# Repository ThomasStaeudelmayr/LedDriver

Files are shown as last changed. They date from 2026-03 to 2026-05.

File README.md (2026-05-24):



This repository contains two distinct 4-channel LED driver hardware designs controlled by an **ESP32-S3 Zero**. Both versions support pulse-width modulation dimming.

- **Constant Current (CC) Driver:** Designed for high-power LEDs (like the Cree XLamp Color Series) that require current regulation.
    
- **Constant Voltage (CV) Driver:** Features 4 power MOSFETs designed for dimming standard 12V/24V RGBW LED strips.

## Hardware
### LED Driver CC

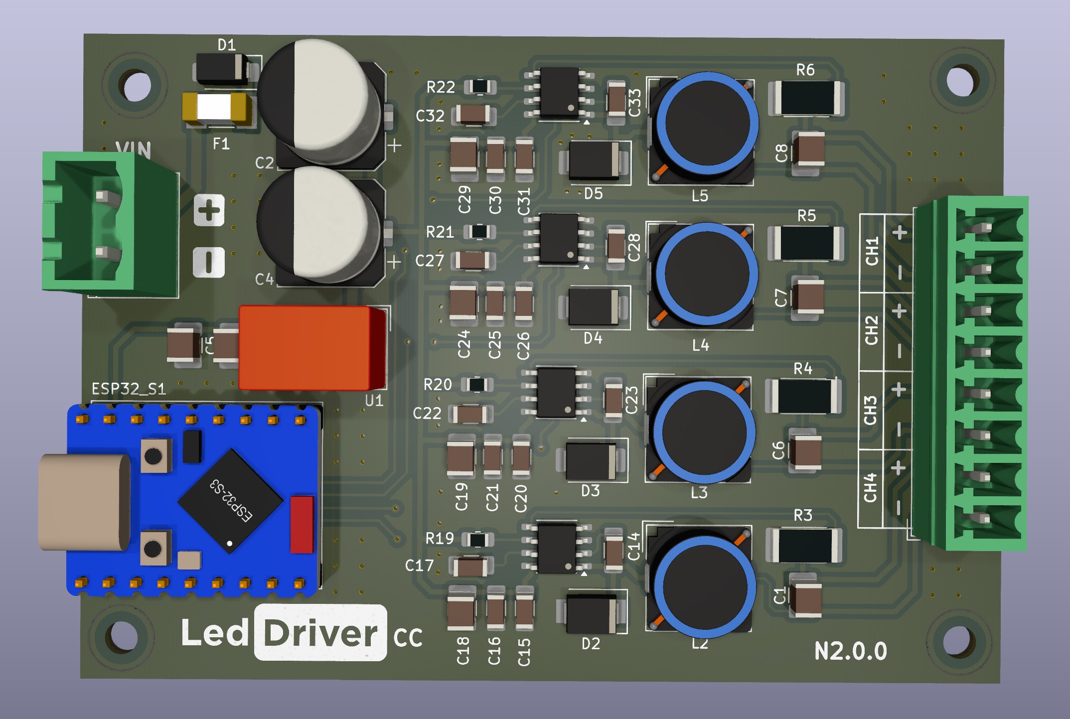
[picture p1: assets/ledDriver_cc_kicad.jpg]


The CC version is built around the **LM3404** LED driver IC. This is a step-down switching regulator that drives the connected LEDs in constant current mode, eliminating the need for current-limiting resistors and increasing system efficiency.
#### Current Sense Resistor Calculation
The maximum forward current ($I_F$) delivered to the LEDs is determined by the value of the sense resistor ($R_{SNS}$) connected to the `CS` pin. Use the following formula to select your resistor value:

$$R_{SNS} = \frac{V_{REF}}{I_F} = \frac{0.2\text{ V}}{I_F}$$

Using a 0.2 $\Omega$ resistor sets the maximum forward current to 1.0 A.

#### Parts
| Part name | Quantity | Order number | Distributor |
| --- | --- | --- | --- |
| ESP32-S3-Zero | 1 | B0GV459V87 | Amazon |
| LM3404 | 4 | LM 3404 MA | Reichelt |
| DK_SLF10145 47uH | 4 | 810-SLF10145T | Mouser |
| 0R2 2512 | 4 | 708-RNCL2512FTR200 | Mouser |
| SMAJ40A | 4 | 652-SMAJ40A | Mouser |
| DCDC Converter | 1 | LME78_05-1.0 | Reichelt |
| MCV_1,5_8-G-3.81 | 1 | 220-4888 | RS |
| Fuse 5A | 1 | 576-0454005.NR | Mouser |
| MSTBVA 2-G 5,08 | 1 | STBVA 2-G 5,08 | Reichelt |
| Capacitor 470uF 10x10 25V | 2 | - | - |
| Capacitor 470nF 1210 | 4 | - | - |
| Capacitor 2.2uF  1206 | 4 | - | - |
| Capacitor 100nF 1206 | 8 | - | - |
| Capacitor 10uF 1210 | 6 | - | - |
| Resistor 500k 0805 | 4 | - | - |

### LED Driver CV

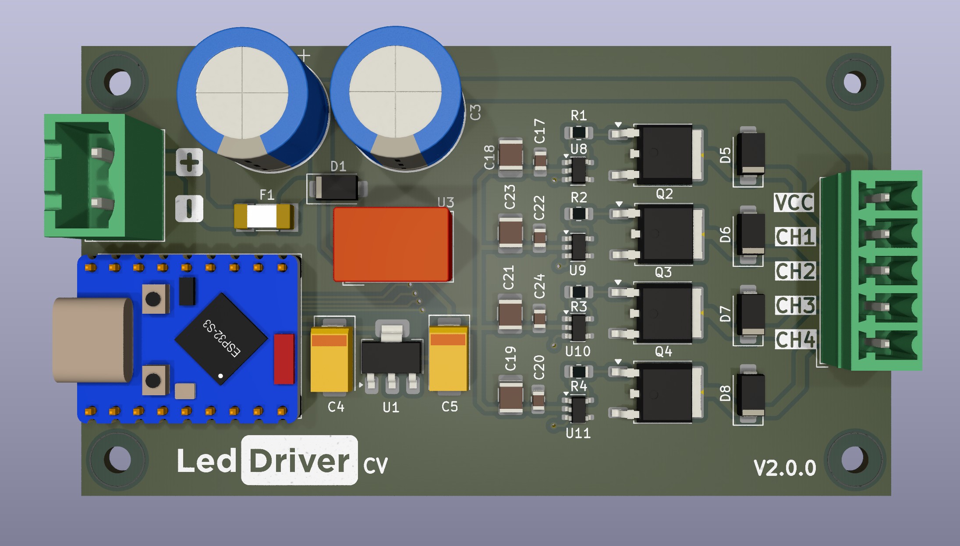
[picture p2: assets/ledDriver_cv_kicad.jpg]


The constant voltage version is designed for standard 12V/24V RGBW LED strips with integrated current-limiting resistors, utilizing 4 power MOSFETs as low-side switches. Dedicated gate drivers rapidly charge the MOSFET gate capacitance. The resulting fast rise and fall times minimize switching power losses during high-frequency PWM operation.
#### Parts
| Part name | Quantity | Order number | Distributor |
| --- | --- | --- | --- |
| ESP32-S3-Zero | 1 | B0GV459V87 | Amazon |
| MCV_1,5_5-G-3.81 | 1 | 651-1803455 | Mouser |
| MSTBVA 2-G 5,08 | 1 | STBVA 2-G 5,08 | Reichelt |
| Capacitor 470uF | 2 | FR-A 470U 63B | Reichelt |
| SMAJ40A | 5 | 652-SMAJ40A | Mouser |
| Tantal 7343 100uF | 2 | 80-T495D107M16ATE060 | Mouser |
| 5V LDO | 1 | 511-LD1117S50 | Mouser |
| 9V DCDC Converter | 1 | TSRN 1-2490 | Reichelt |
| MCP1416 SOT-23-5 | 4 | 579-MCP1416RTEOTVAO  | Mouser |
| Mosfet STD80N6F6 | 4 | 511-STD80N6F6 | Mouser |
| Fuse 5A | 1 | 576-0454005.NR | Mouser |
| Capacitor 10uF 1210  | 4 | - | - |
| Capacitor 100nF 0805 | 4 | - | - |
| Resistor 10R 0805 | 4 | - | - |

## Software 

### ESP-NOW Control Example

The PC sends color values over a USB serial connection to the **Led Driver Bridge**, which then wirelessly sends those values to the **Led Driver Receiver**. 
#### 1. Get the Receiver's MAC Address
To pair the devices, you need the unique MAC address of the receiver board.
1. Upload the **Receiver Code** to your LED driver board.
2. Open the Serial Monitor. On startup, the ESP32 will print its MAC address.
3. Copy this address; you will need it for the transmitter code.
    
#### 2. Transmitter/Bridge Configuration & Operation
The transmitter connects to your PC via USB, listens for incoming serial data, and forwards it wirelessly.
1. Open the **Transmitter Code**.
2. Replace the placeholder bytes with your receiver's MAC address
3. Upload the code to the transmitter ESP32. 

```cpp
// Example: Replace with your actual receiver MAC address
uint8_t broadcastAddress[] = {0x34, 0xB7, 0xDA, 0x5B, 0x58, 0xE0};
```

#### Sending Control Commands 
The bridge ESP expects a single string formatted as `R:G:B:W` followed by a newline character (`\n`).  

**Example:** `1024:255:150:360` 

You can type this manually into the Arduino Serial Monitor or automate it using a program. This repository contains two python and one html example that generate the rgbw values. Once the transmitter gets a valid message, it splits the string into individual color values and sends them out over ESP-NOW. 

**LedDriver_web_app_rgbw.html** - control leds via a browser 
**LedDriver_control_hsv.py** - control leds via a python script 
**LedDriver_rgbw_waves.py** - python script that generates led animation 

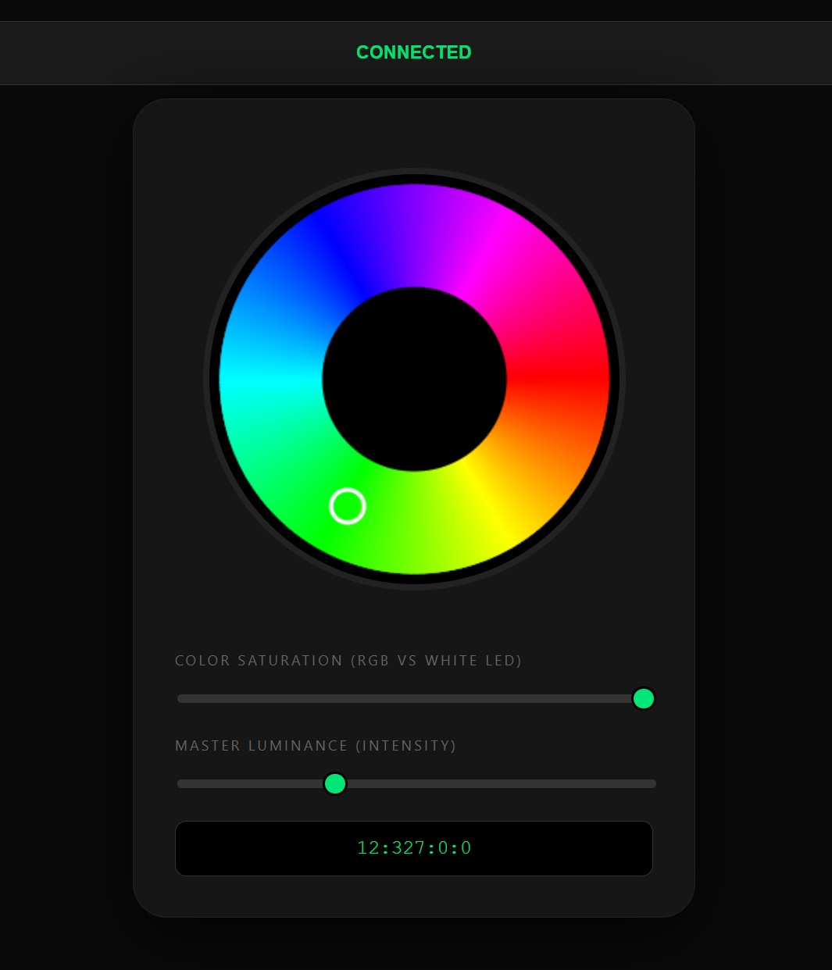
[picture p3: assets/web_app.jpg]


#### How to execute Python Scripts 
1. In folder open CMD
2. generate environment (python -m venv env)
3. open environment via activate.bat
4. install modules using pip
5. execute 

### Web Server Example
The Web Server example eliminates the need for a dedicated transmitter controller. The ESP32 on the driver board will act as a web server. After altering the Wi-Fi name and password and uploading the code the leds can be controlled on: http://ledcontrol.local

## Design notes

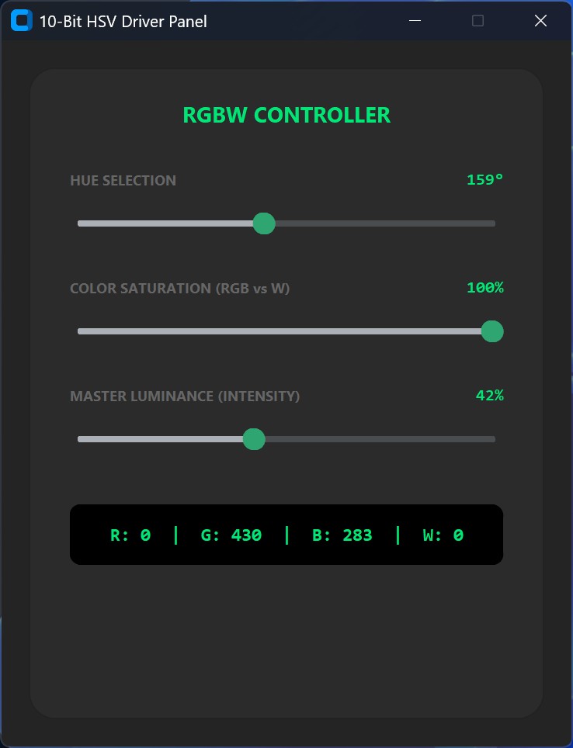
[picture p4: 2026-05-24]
assets/python_hsv_control.jpg

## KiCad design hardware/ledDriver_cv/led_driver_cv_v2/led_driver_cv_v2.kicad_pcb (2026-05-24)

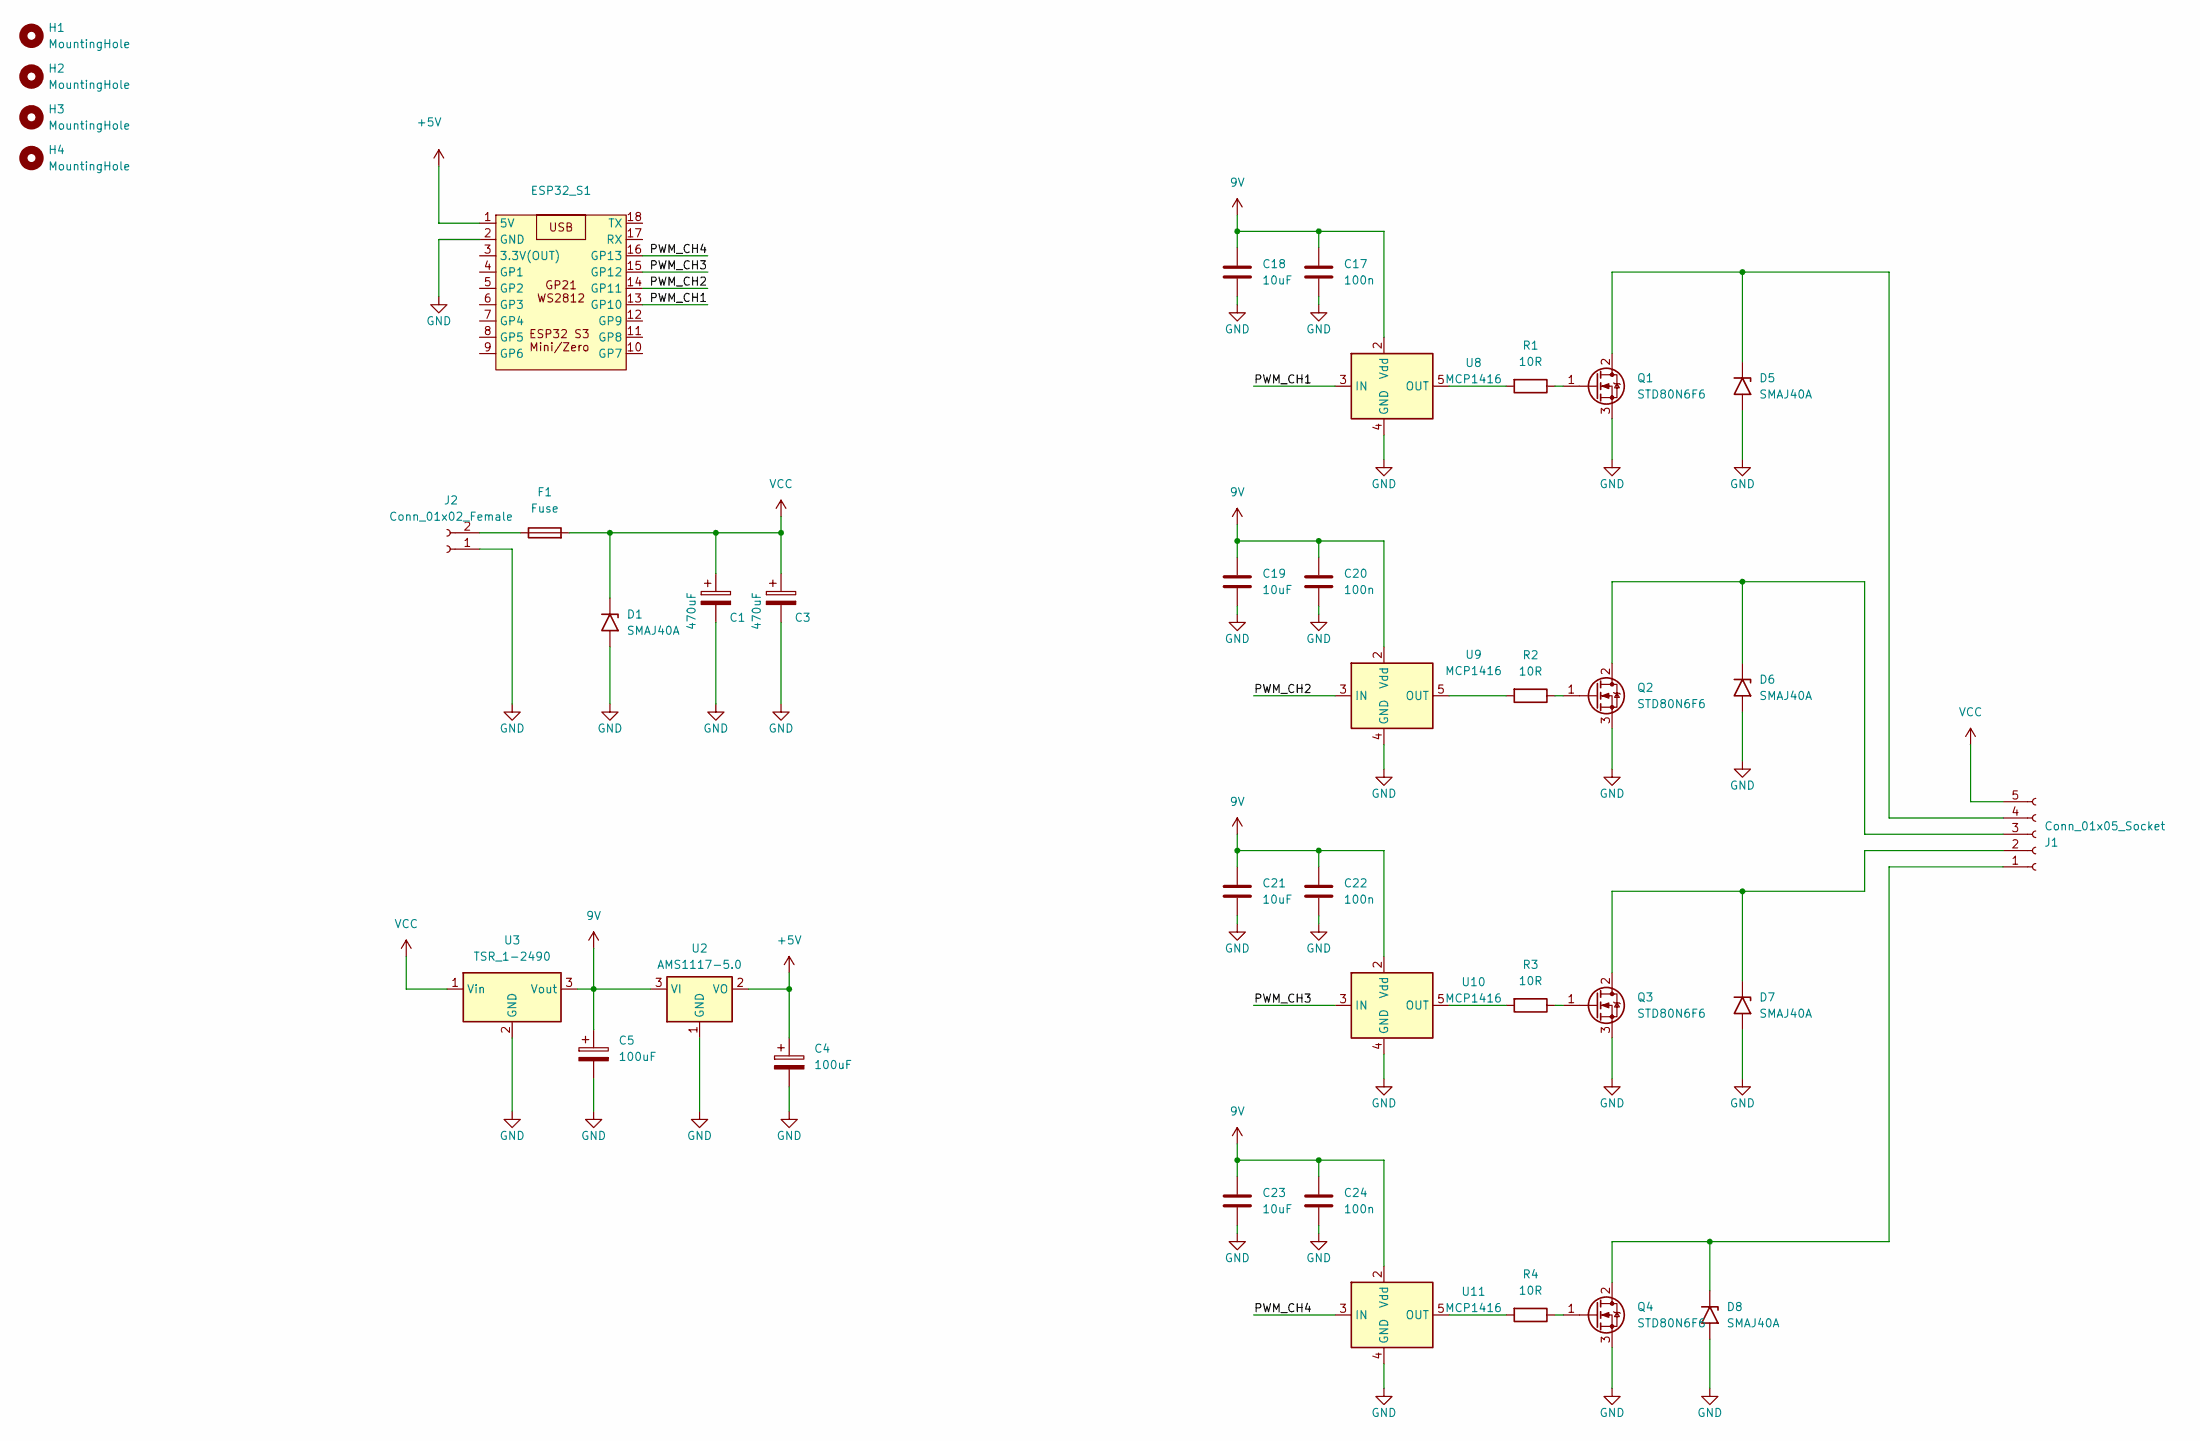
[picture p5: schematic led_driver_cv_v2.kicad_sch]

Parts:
C1, C3: 470uF; CP_Radial_D13.0mm_P5.00mm
C4, C5: 100uF; CP_EIA-7343-40_Kemet-Y_HandSolder
C17, C20, C22, C24: 100n; C_0805_2012Metric_Pad1.18x1.45mm_HandSolder
C18, C19, C21, C23: 10uF; C_1210_3225Metric_Pad1.33x2.70mm_HandSolder
D1, D5, D6, D7, D8: SMAJ40A; D_SMA
ESP32_S1: ESP32-S3-Zero
F1: Fuse; Fuse_Littelfuse-NANO2-451_453
H1: MountingHole; MountingHole_2.5mm
H2, H3, H4: MountingHole; MountingHole_3mm
J1: Conn_01x05_Socket; PhoenixContact_MCV_1,5_5-G-3.81_1x05_P3.81mm_Vertical
J2: Conn_01x02_Female; PhoenixContact_MSTBVA_2,5_2-G-5,08_1x02_P5.08mm_Vertical
Q1, Q2, Q3, Q4: STD80N6F6; TO-252-2
R1, R2, R3, R4: 10R; R_0805_2012Metric_Pad1.20x1.40mm_HandSolder
U2: AMS1117-5.0; SOT-223-3_TabPin2
U3: TSR_1-2490; Converter_DCDC_TRACO_TSR-1_THT
U8, U9, U10, U11: MCP1416; SOT-23-5

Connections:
9V: C5.1, C17.1, C18.1, C19.1, C20.1, C21.1, C22.1, C23.1, C24.1, U2.3 (VI), U3.3 (Vout), U8.2 (Vdd), U9.2 (Vdd), U10.2 (Vdd), U11.2 (Vdd)
+5V: C4.1, ESP32_S1.1 (5V), U2.2 (VO)
/PWM_CH1: ESP32_S1.13 (GP10), U8.3 (IN)
/PWM_CH2: ESP32_S1.14 (GP11), U9.3 (IN)
/PWM_CH3: ESP32_S1.15 (GP12), U10.3 (IN)
/PWM_CH4: ESP32_S1.16 (GP13), U11.3 (IN)
GND: C1.2, C3.2, C4.2, C5.2, C17.2, C18.2, C19.2, C20.2, C21.2, C22.2, C23.2, C24.2, D1.2 (A2), D5.2 (A2), D6.2 (A2), D7.2 (A2), D8.2 (A2), ESP32_S1.2 (GND), J2.1, Q1.3 (S), Q2.3 (S), Q3.3 (S), Q4.3 (S), U2.1 (GND), U3.2 (GND), U8.4 (GND), U9.4 (GND), U10.4 (GND), U11.4 (GND)
unnamed: D5.1 (A1), J1.4, Q1.2 (D)
unnamed: D6.1 (A1), J1.3, Q2.2 (D)
unnamed: D7.1 (A1), J1.2, Q3.2 (D)
unnamed: D8.1 (A1), J1.1, Q4.2 (D)
unnamed: F1.1, J2.2
unnamed: Q1.1 (G), R1.1
unnamed: Q2.1 (G), R2.1
unnamed: Q3.1 (G), R3.1
unnamed: Q4.1 (G), R4.1
unnamed: R1.2, U8.5 (OUT)
unnamed: R2.2, U9.5 (OUT)
unnamed: R3.2, U10.5 (OUT)
unnamed: R4.2, U11.5 (OUT)
VCC: C1.1, C3.1, D1.1 (A1), F1.2, J1.5, U3.1 (Vin)

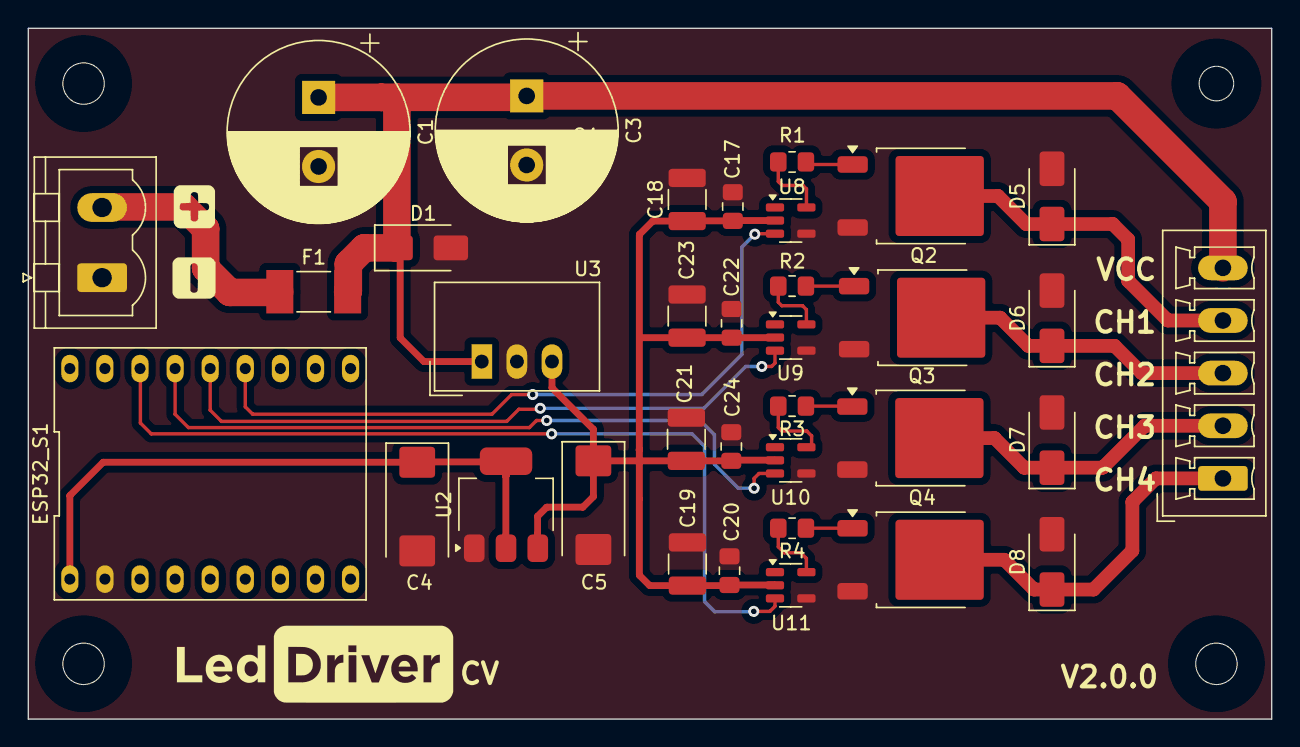
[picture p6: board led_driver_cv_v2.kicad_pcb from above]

Board: 2 copper layers, 90.0 x 50.0 mm, 39 parts (0 on the bottom side), 21 nets.

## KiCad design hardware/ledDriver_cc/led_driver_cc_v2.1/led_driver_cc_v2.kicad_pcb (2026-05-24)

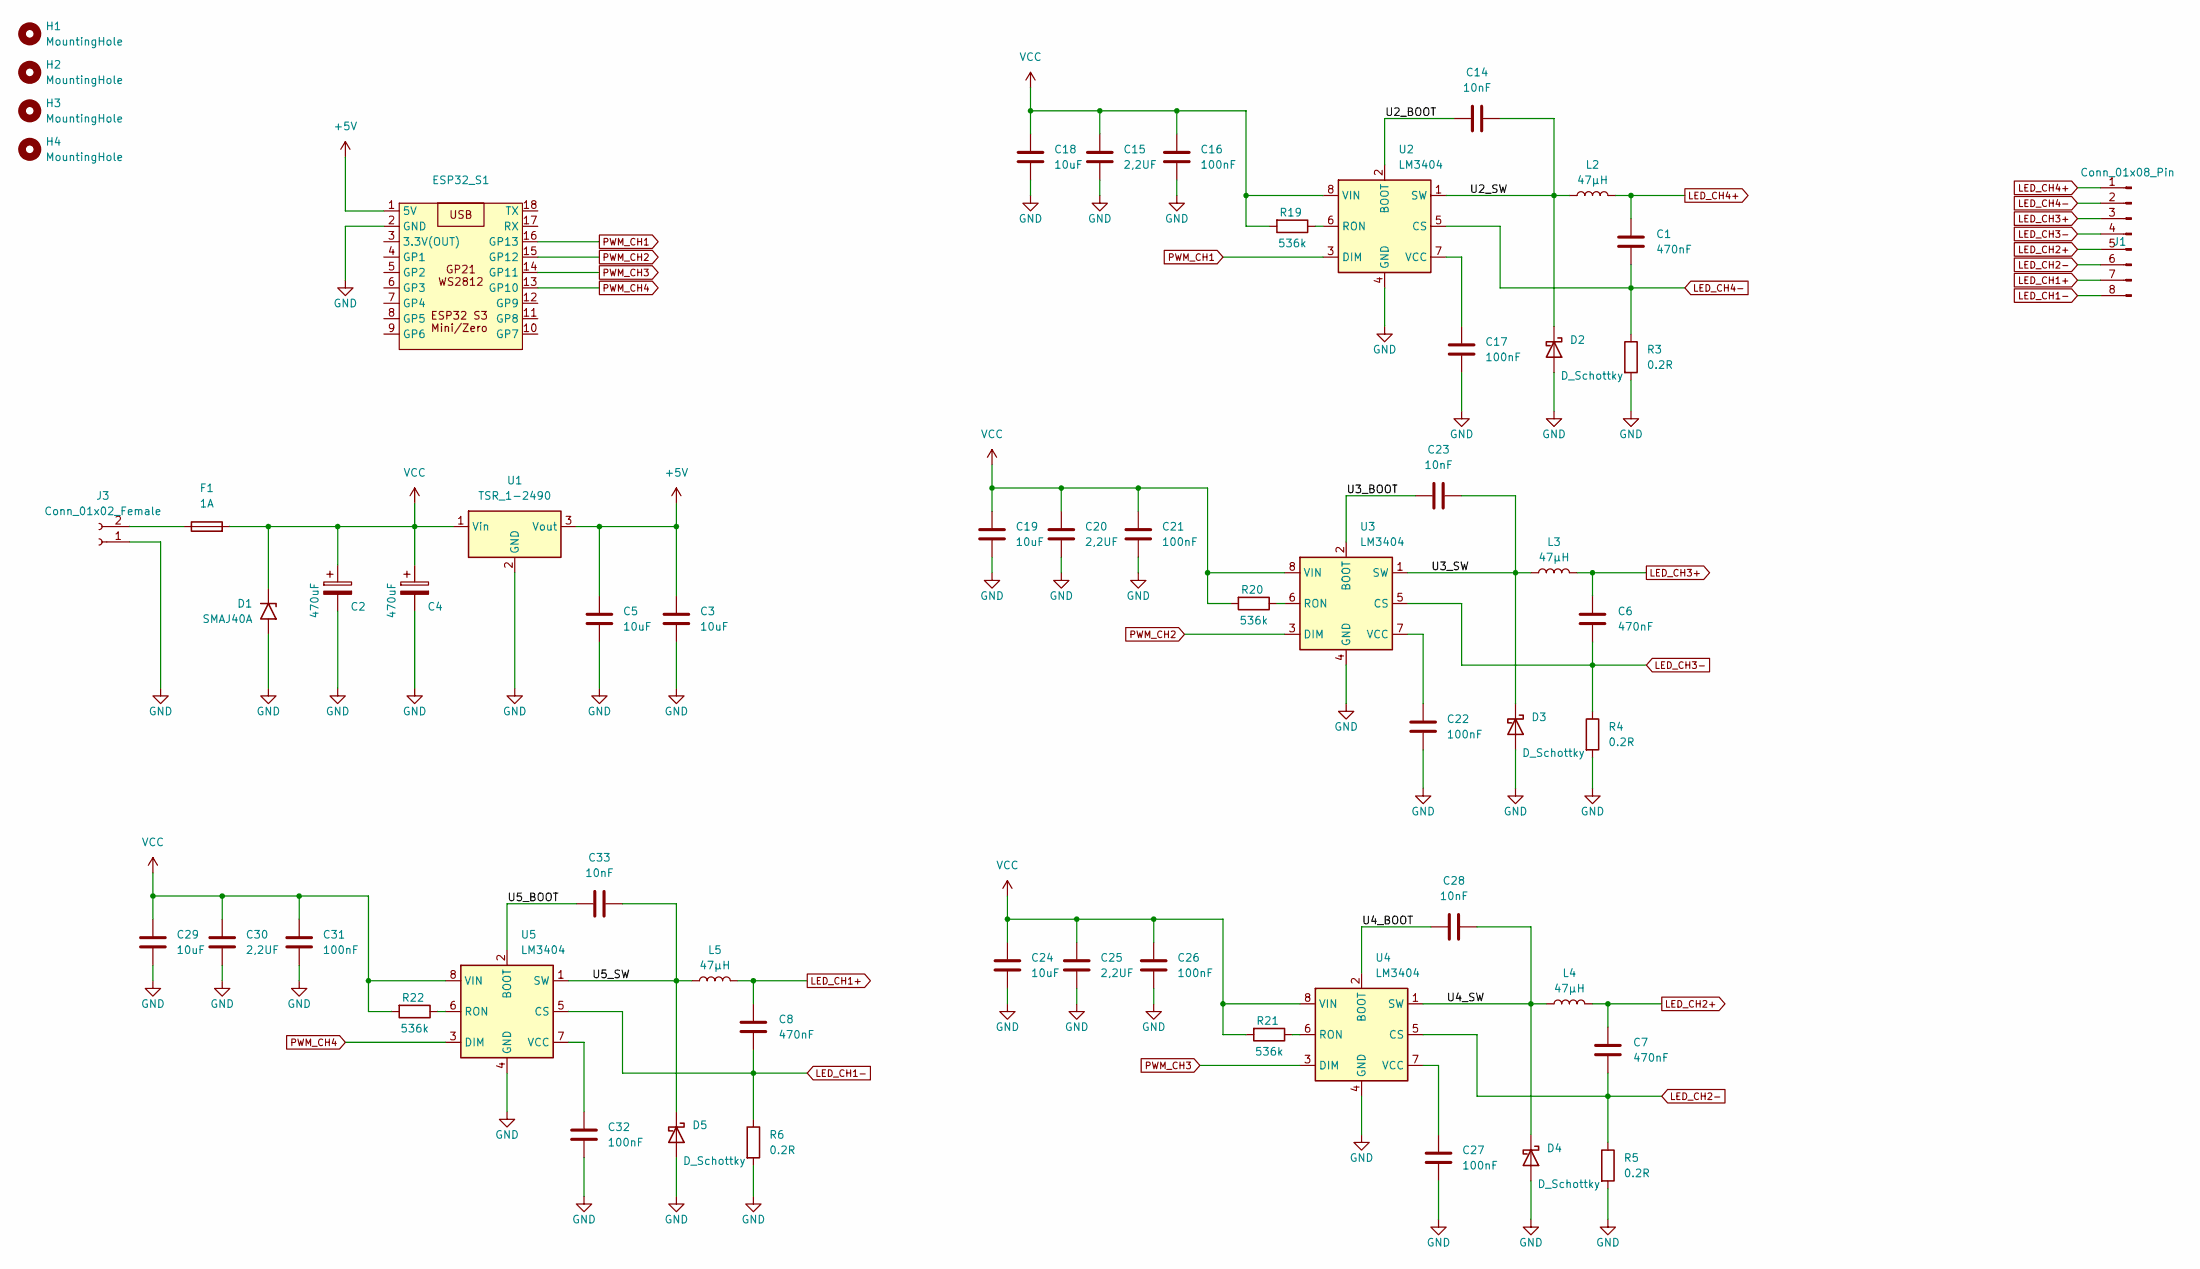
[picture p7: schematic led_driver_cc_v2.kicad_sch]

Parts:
C1, C6, C7, C8: 470nF; C_1210_3225Metric_Pad1.33x2.70mm_HandSolder
C2, C4: 470uF; CP_Elec_10x10
C3, C5, C18, C19, C24, C29: 10uF; C_1210_3225Metric_Pad1.33x2.70mm_HandSolder
C14, C23, C28, C33: 10nF; C_1206_3216Metric_Pad1.33x1.80mm_HandSolder
C15, C20, C25, C30: 2,2UF; C_1206_3216Metric_Pad1.33x1.80mm_HandSolder
C16, C17, C21, C22, C26, C27, C31, C32: 100nF; C_1206_3216Metric_Pad1.33x1.80mm_HandSolder
D1: SMAJ40A; D_SMA
D2, D3, D4, D5: D_Schottky; D_SMB
ESP32_S1: ESP32-S3-Zero
F1: 1A; Fuse_Littelfuse-NANO2-451_453
H1, H2, H3, H4: MountingHole; MountingHole_3.2mm_M3
J1: Conn_01x08_Pin; PhoenixContact_MCV_1,5_8-G-3.81_1x08_P3.81mm_Vertical
J3: Conn_01x02_Female; PhoenixContact_MSTBVA_2,5_2-G_1x02_P5.00mm_Vertical
L2, L3, L4, L5: 47µH; L_TDK_SLF10145
R3, R4, R5, R6: 0.2R; R_2512_6332Metric_Pad1.40x3.35mm_HandSolder
R19, R20, R21, R22: 536k; R_0805_2012Metric_Pad1.20x1.40mm_HandSolder
U1: TSR_1-2490; Converter_DCDC_TRACO_TSR-1_THT
U2, U3, U4, U5: LM3404; SOIC-8_3.9x4.9mm_P1.27mm

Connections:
+5V: C3.1, C5.1, ESP32_S1.1 (5V), U1.3 (Vout)
/U2_BOOT: C14.1, U2.2 (BOOT)
/U2_SW: C14.2, D2.1 (K), L2.1, U2.1 (SW)
/U3_BOOT: C23.1, U3.2 (BOOT)
/U3_SW: C23.2, D3.1 (K), L3.1, U3.1 (SW)
/U4_BOOT: C28.1, U4.2 (BOOT)
/U4_SW: C28.2, D4.1 (K), L4.1, U4.1 (SW)
/U5_BOOT: C33.1, U5.2 (BOOT)
/U5_SW: C33.2, D5.1 (K), L5.1, U5.1 (SW)
GND: C2.2, C3.2, C4.2, C5.2, C15.1, C16.1, C17.1, C18.1, C19.1, C20.1, C21.1, C22.1, C24.1, C25.1, C26.1, C27.1, C29.1, C30.1, C31.1, C32.1, D1.2 (A2), D2.2 (A), D3.2 (A), D4.2 (A), D5.2 (A), ESP32_S1.2 (GND), J3.1, R3.2, R4.2, R5.2, R6.2, U1.2 (GND), U2.4 (GND), U3.4 (GND), U4.4 (GND), U5.4 (GND)
LED_CH1+: C8.1, J1.7, L5.2
LED_CH1-: C8.2, J1.8, R6.1, U5.5 (CS)
LED_CH2+: C7.1, J1.5, L4.2
LED_CH2-: C7.2, J1.6, R5.1, U4.5 (CS)
LED_CH3+: C6.1, J1.3, L3.2
LED_CH3-: C6.2, J1.4, R4.1, U3.5 (CS)
LED_CH4+: C1.1, J1.1, L2.2
LED_CH4-: C1.2, J1.2, R3.1, U2.5 (CS)
unnamed: F1.1, J3.2
unnamed: R19.1, U2.6 (RON)
unnamed: C17.2, U2.7 (VCC)
unnamed: R20.1, U3.6 (RON)
unnamed: C22.2, U3.7 (VCC)
unnamed: R21.1, U4.6 (RON)
unnamed: C27.2, U4.7 (VCC)
unnamed: R22.1, U5.6 (RON)
unnamed: C32.2, U5.7 (VCC)
PWM_CH1: ESP32_S1.16 (GP13), U2.3 (DIM)
PWM_CH2: ESP32_S1.15 (GP12), U3.3 (DIM)
PWM_CH3: ESP32_S1.14 (GP11), U4.3 (DIM)
PWM_CH4: ESP32_S1.13 (GP10), U5.3 (DIM)
VCC: C2.1, C4.1, C15.2, C16.2, C18.2, C19.2, C20.2, C21.2, C24.2, C25.2, C26.2, C29.2, C30.2, C31.2, D1.1 (A1), F1.2, R19.2, R20.2, R21.2, R22.2, U1.1 (Vin), U2.8 (VIN), U3.8 (VIN), U4.8 (VIN), U5.8 (VIN)

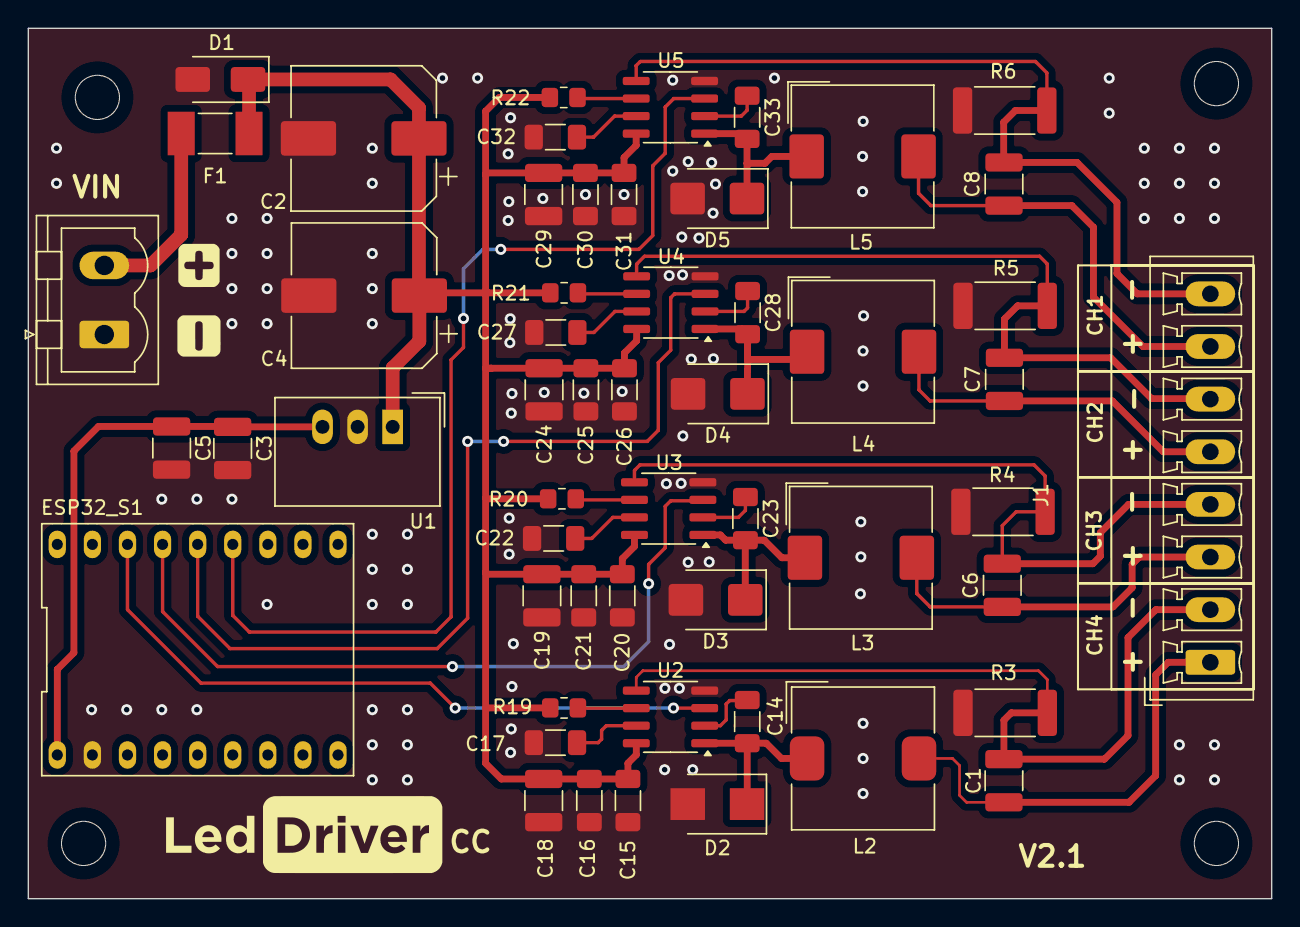
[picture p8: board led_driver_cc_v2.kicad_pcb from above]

Board: 2 copper layers, 90.0 x 63.0 mm, 58 parts (0 on the bottom side), 32 nets.

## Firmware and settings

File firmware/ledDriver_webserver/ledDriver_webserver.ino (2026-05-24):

/*
 * ====================================================================
 * Project:      RGBW Led Driver Controller
 * Description:  Hosts an internal web page allowing real-time adjustment
 * of 4 PWM channels.
 * Target Board: ESP32-S3 Zero
 * ====================================================================
 */

#include <WiFi.h>
#include <WebServer.h>
#include <ESPmDNS.h>

// --- WiFi Credentials ---
const char* ssid = "YOUR_WIFI_SSID";
const char* password = "YOUR_WIFI_PASSWORD";


// --- Pin & PWM Definitions ---
const int pins[] = {10, 11, 12, 13}; 

// Locked to your target hardware parameters
const uint32_t PWM_FREQ = 1000;  // 1 kHz Frequency
const uint8_t PWM_RES   = 10;    // 10-bit Resolution (0 - 1023)

WebServer server(80);

// HTML Dashboard String
const char PAGE_MAIN[] PROGMEM = R"=====(
<!DOCTYPE html>
<html>
<head>
    <meta name="viewport" content="width=device-width, initial-scale=1">
    <title>LED Dashboard</title>
    <style>
        body { font-family: sans-serif; text-align: center; background: #121212; color: white; padding: 20px; }
        .card { background: #1e1e1e; padding: 15px; border-radius: 12px; margin: 10px auto; max-width: 350px; border: 1px solid #333; }
        h2 { color: #00adb5; }
        input[type=range] { width: 100%; accent-color: #00adb5; cursor: pointer; }
        .val-display { font-size: 1.1em; margin-top: 5px; color: #00adb5; font-weight: bold; }
    </style>
</head>
<body>
    <h2>Led Driver Control</h2>
    <div class="card">
        <p>Channel 1 (red) </p>
        <input type="range" min="0" max="1023" value="0" oninput="update(1, this.value)">
        <div class="val-display" id="val1">0</div>
    </div>
    <div class="card">
        <p>Channel 2 (green)</p>
        <input type="range" min="0" max="1023" value="0" oninput="update(2, this.value)">
        <div class="val-display" id="val2">0</div>
    </div>
    <div class="card">
        <p>Channel 3 (blue)</p>
        <input type="range" min="0" max="1023" value="0" oninput="update(3, this.value)">
        <div class="val-display" id="val3">0</div>
    </div>
    <div class="card">
        <p>Channel 4 (white)</p>
        <input type="range" min="0" max="1023" value="0" oninput="update(4, this.value)">
        <div class="val-display" id="val4">0</div>
    </div>

    <script>
        function update(ch, val) {
            document.getElementById('val' + ch).innerHTML = val;
            fetch(`/set?ch=${ch}&val=${val}`);
        }
    </script>
</body>
</html>
)=====";

void handleRoot() {
  server.send(200, "text/html", PAGE_MAIN);
}

void handleUpdate() {
  if (server.hasArg("ch") && server.hasArg("val")) {
    int ch = server.arg("ch").toInt();
    int val = server.arg("val").toInt();
    
    if (ch >= 1 && ch <= 4) {
      // Guard bounds to keep values within 10-bit hardware boundaries
      if(val > 1023) val = 1023;
      if(val < 0) val = 0;

      // Updated native ESP32 API call for writing duty cycle changes
      ledcWrite(pins[ch-1], val);
    }
    server.send(200, "text/plain", "OK");
  }
}

void setup() {
  Serial.begin(115200);
  
  // Initialize pins using the modern ESP32 LEDC API
  for(int i = 0; i < 4; i++) {
    // Under Arduino ESP32 core v3.x+, ledcAttach combines initialization and routing automatically
    ledcAttach(pins[i], PWM_FREQ, PWM_RES);
    ledcWrite(pins[i], 0); // Start off
  }

  // Connect to WiFi
  WiFi.begin(ssid, password);
  Serial.print("Connecting to Wi-Fi");
  while (WiFi.status() != WL_CONNECTED) {
    delay(500);
    Serial.print(".");
  }
  Serial.println("\nConnected!");

  // --- START MDNS ---
  if (MDNS.begin("ledcontrol")) {
    Serial.println("Access dashboard at: http://ledcontrol.local");
  }

  Serial.print("IP Address: ");
  Serial.println(WiFi.localIP());

  server.on("/", handleRoot);
  server.on("/set", handleUpdate);
  server.begin();
}

void loop() {
  server.handleClient();
}

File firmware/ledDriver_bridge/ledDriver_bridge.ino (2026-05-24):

/*
 * ====================================================================
 * Project:      ESP-NOW Led Driver Bridge
 * Description:  Parses raw serial strings formatted as "R:G:B:W" and 
 *               transmits the parsed values via ESP-NOW to a led driver receiver.
 * Target Board: ESP32-S3 Zero
 * Author:       Thomas Stäudelmayr
 * Date:         May 2026
 * ====================================================================
 */

#include <WiFi.h>
#include <esp_now.h>

#define MAX_PWM 1023 //vaues above this will be clamped

// MAC Address of target ESP32-S3 receiver
uint8_t broadcastAddress[] = {0x34, 0xB7, 0xDA, 0x5B, 0x58, 0xE0};

// Structure for outgoing RGBW data (Must match receiver structure exactly)
typedef struct struct_message {
  int red;
  int green;
  int blue;
  int white;
} struct_message;

struct_message myData;
String inputString = ""; 
bool stringComplete = false;

// Callback triggered when a packet is sent
void OnDataSent(const esp_now_send_info_t *info, esp_now_send_status_t status) {
  Serial.print("\r\nLast Packet Send Status:\t");
  Serial.println(status == ESP_NOW_SEND_SUCCESS ? "Delivery Success" : "Delivery Fail");
}

void setup() {
  Serial.begin(115200);
  WiFi.mode(WIFI_STA);

  if (esp_now_init() != ESP_OK) {
    Serial.println("Error initializing ESP-NOW");
    return;
  }

  // Register send callback
  esp_now_register_send_cb(OnDataSent);

  // Initialize and register peer device
  esp_now_peer_info_t peerInfo;
  memset(&peerInfo, 0, sizeof(peerInfo)); 
  
  memcpy(peerInfo.peer_addr, broadcastAddress, 6);
  peerInfo.channel = 0;  
  peerInfo.encrypt = false;
  
  if (esp_now_add_peer(&peerInfo) != ESP_OK){
    Serial.println("Failed to add peer");
    return;
  }

  inputString.reserve(64);
  Serial.println("Sender Ready. Format: R:G:B:W");
}

void loop() {
  // Read incoming bytes from the Serial Buffer
  while (Serial.available()) {
    char inChar = (char)Serial.read();
    if (inChar == '\n' || inChar == '\r') {
      if (inputString.length() > 0) {
        stringComplete = true;
      }
    } else {
      inputString += inChar;
    }
  }

  // Parse and transmit when a newline or carriage return is detected
  if (stringComplete) {
    inputString.trim();

    // Check for identification query
    if (inputString.equalsIgnoreCase("deviceinfo")) {
      Serial.println("leddriver_bridge");
    } else {
      // Find delimiters for parsing string substring chunks
      int sep1 = inputString.indexOf(':');
      int sep2 = inputString.indexOf(':', sep1 + 1);
      int sep3 = inputString.indexOf(':', sep2 + 1);

      if (sep1 > 0 && sep2 > sep1 && sep3 > sep2) {
        myData.red   = constrain(inputString.substring(0, sep1).toInt(), 0, MAX_PWM);
        myData.green = constrain(inputString.substring(sep1 + 1, sep2).toInt(), 0, MAX_PWM);
        myData.blue  = constrain(inputString.substring(sep2 + 1, sep3).toInt(), 0, MAX_PWM);
        myData.white = constrain(inputString.substring(sep3 + 1).toInt(), 0, MAX_PWM);
        // Blast data package over ESP-NOW
        esp_err_t result = esp_now_send(broadcastAddress, (uint8_t *) &myData, sizeof(myData));
        
        if (result != ESP_OK) {
          Serial.println("Error sending the data");
        }
      } else {
        Serial.println("Invalid Format! Use R:G:B:W");
      }
    }
    
    // Clear string state to receive next batch
    inputString = "";
    stringComplete = false;
  }
}

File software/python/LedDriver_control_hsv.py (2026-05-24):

import customtkinter as ctk
from PIL import Image, ImageTk
import serial
import time
import math
import serial.tools.list_ports

# Set UI Theme styling
ctk.set_appearance_mode("Dark")
ctk.set_default_color_theme("green")

def find_led_driver_port(baudrate=115200):
    print("Searching for LED driver...")
    ports = serial.tools.list_ports.comports()
    for port in ports:
        try:
            test_ser = serial.Serial(port.device, baudrate, timeout=1, write_timeout=1)
            test_ser.setDTR(True)
            test_ser.setRTS(True)
            time.sleep(1.5) 
            test_ser.reset_input_buffer()
            test_ser.write(b"deviceinfo\n")
            time.sleep(0.2)
            
            response = test_ser.readline().decode('utf-8', errors='ignore').strip().lower()
            if response == "leddriver_bridge":
                print(f"LED driver found on {port.device}")
                return test_ser  
            test_ser.close()
        except (serial.SerialException, UnicodeDecodeError, PermissionError):
            pass
    print("LED driver not found.")
    return None

def calculate_rgbw_10bit(h_deg, saturation, luminance):
    """
    Converts HSV parameters using independent master-dimmer logic.
    Outputs true 10-bit values (0-1023).
    """
    max_pwm = 1023

    # 1. Calculate vibrant chroma from Hue angle
    h_prime = h_deg / 60
    x = 1 - abs((h_prime % 2) - 1)
    
    r_chroma, g_chroma, b_chroma = 0.0, 0.0, 0.0
    if   0 <= h_prime < 1: r_chroma, g_chroma, b_chroma = 1.0, x, 0.0
    elif 1 <= h_prime < 2: r_chroma, g_chroma, b_chroma = x, 1.0, 0.0
    elif 2 <= h_prime < 3: r_chroma, g_chroma, b_chroma = 0.0, 1.0, x
    elif 3 <= h_prime < 4: r_chroma, g_chroma, b_chroma = 0.0, x, 1.0
    elif 4 <= h_prime < 5: r_chroma, g_chroma, b_chroma = x, 0.0, 1.0
    elif 5 <= h_prime < 6: r_chroma, g_chroma, b_chroma = 1.0, 0.0, x

    # 2. Crossfade color vs white based strictly on saturation position
    r_mix = r_chroma * saturation
    g_mix = g_chroma * saturation
    b_mix = b_chroma * saturation
    w_mix = (1.0 - saturation)

    # 3. Apply the luminance slider as a pure master dimmer scale across all channels
    return (
        int(round(r_mix * luminance * max_pwm)),
        int(round(g_mix * luminance * max_pwm)),
        int(round(b_mix * luminance * max_pwm)),
        int(round(w_mix * luminance * max_pwm))
    )

def update_output(*args):
    # Fetch slider attributes
    h = hue_slider.get()
    s = sat_slider.get()
    v = val_slider.get()
    
    # Calculate 10-bit RGBW
    r, g, b, w = calculate_rgbw_10bit(h, s, v)
    
    # Format and send over serial connection
    msg = f"{r}:{g}:{b}:{w}\n"
    if ser:
        ser.write(msg.encode())
    
    # Update UI Labels
    hue_val_label.configure(text=f"{int(h)}°")
    sat_val_label.configure(text=f"{int(s*100)}%")
    val_val_label.configure(text=f"{int(v*100)}%")
    debug_display.configure(text=f"R: {r}  |  G: {g}  |  B: {b}  |  W: {w}")

# --- GUI Core Layout ---

ser = find_led_driver_port()
if ser is None:
    print("Exiting: No active hardware device discovered.")
    exit(1)

app = ctk.CTk()
app.title("10-Bit HSV Led Driver Panel")
app.geometry("420x520")
app.resizable(False, False)

# Main container card frame
main_card = ctk.CTkFrame(master=app, corner_radius=20, border_width=1, border_color="#222222")
main_card.pack(fill="both", expand=True, padx=20, pady=20)

# Title Header
title_label = ctk.CTkLabel(master=main_card, text="RGBW CONTROLLER", font=("Segoe UI", 16, "bold"), text_color="#00e676")
title_label.pack(pady=(20, 10))

# --- SLIDER 1: HUE ---
hue_frame = ctk.CTkFrame(master=main_card, fg_color="transparent")
hue_frame.pack(fill="x", padx=30, pady=10)

hue_title = ctk.CTkLabel(master=hue_frame, text="HUE SELECTION", font=("Segoe UI", 10, "bold"), text_color="#666666")
hue_title.pack(side="left")
hue_val_label = ctk.CTkLabel(master=hue_frame, text="0°", font=("Consolas", 12, "bold"), text_color="#00e676")
hue_val_label.pack(side="right")

hue_slider = ctk.CTkSlider(master=main_card, from_=0, to=359, number_of_steps=360, command=update_output)
hue_slider.set(0)
hue_slider.pack(fill="x", padx=30, pady=(0, 15))

# --- SLIDER 2: SATURATION ---
sat_frame = ctk.CTkFrame(master=main_card, fg_color="transparent")
sat_frame.pack(fill="x", padx=30, pady=10)

sat_title = ctk.CTkLabel(master=sat_frame, text="COLOR SATURATION (RGB vs W)", font=("Segoe UI", 10, "bold"), text_color="#666666")
sat_title.pack(side="left")
sat_val_label = ctk.CTkLabel(master=sat_frame, text="100%", font=("Consolas", 12, "bold"), text_color="#00e676")
sat_val_label.pack(side="right")

sat_slider = ctk.CTkSlider(master=main_card, from_=0.0, to=1.0, number_of_steps=100, command=update_output)
sat_slider.set(1.0)
sat_slider.pack(fill="x", padx=30, pady=(0, 15))

# --- SLIDER 3: VALUE / BRIGHTNESS ---
val_frame = ctk.CTkFrame(master=main_card, fg_color="transparent")
val_frame.pack(fill="x", padx=30, pady=10)

val_title = ctk.CTkLabel(master=val_frame, text="MASTER LUMINANCE (INTENSITY)", font=("Segoe UI", 10, "bold"), text_color="#666666")
val_title.pack(side="left")
val_val_label = ctk.CTkLabel(master=val_frame, text="100%", font=("Consolas", 12, "bold"), text_color="#00e676")
val_val_label.pack(side="right")

val_slider = ctk.CTkSlider(master=main_card, from_=0.0, to=1.0, number_of_steps=100, command=update_output)
val_slider.set(1.0)
val_slider.pack(fill="x", padx=30, pady=(0, 25))

# --- DATA READOUT TERMINAL ---
debug_display = ctk.CTkLabel(master=main_card, text="R: 0  |  G: 0  |  B: 0  |  W: 0",
                             font=("Consolas", 14, "bold"), text_color="#00e676",
                             fg_color="#000000", height=45, corner_radius=8)
debug_display.pack(fill="x", padx=30, pady=15)

# Initialize application layout state variables
update_output()

app.mainloop()

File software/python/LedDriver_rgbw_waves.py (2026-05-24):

import serial
import time
import math
import serial.tools.list_ports

def find_led_driver_port(baudrate=115200):
    print("Searching for LED driver...")
    ports = serial.tools.list_ports.comports()
    for port in ports:
        try:
            test_ser = serial.Serial(port.device, baudrate, timeout=1, write_timeout=1)
            test_ser.setDTR(True)
            test_ser.setRTS(True)
            time.sleep(1.5) 
            test_ser.reset_input_buffer()
            test_ser.write(b"deviceinfo\n")
            time.sleep(0.2)
            
            response = test_ser.readline().decode('utf-8', errors='ignore').strip().lower()
            if response == "leddriver_bridge":
                print(f"Connected to LED driver on {port.device}")
                return test_ser  
            test_ser.close()
        except (serial.SerialException, UnicodeDecodeError, PermissionError):
            pass
    return None

# Initialize Connection
ser = find_led_driver_port()
if ser is None:
    print("Error: Could not find your ESP32 Transmitter. Check USB cable connection.")
    exit(1)

print("\n--- Starting Color Waves ---")
print("Press Ctrl+C in your terminal to stop the program.\n")

# Wave Animation Variables
step = 0.0
speed = 0.03       # Higher numbers = faster color transitions
max_pwm = 1023     # Target 10-bit ceiling

try:
    while True:
        # Generate independent offset sine waves (-1.0 to 1.0) scaled up to 10-bit amplitudes
        # Math offsets (like + 2.0 or + 4.0) prevent the channels from peaking at the exact same moment
        r = int((math.sin(step) + 1) / 2 * max_pwm)
        g = int((math.sin(step + 2.0) + 1) / 2 * max_pwm)
        b = int((math.sin(step + 4.0) + 1) / 2 * max_pwm)
        
        # Make the White LED pulse slowly on an alternate cadence for ambient background filling
        w = int((math.cos(step * 0.5) + 1) / 2 * max_pwm)

        # Pack and transmit payload
        payload = f"{r}:{g}:{b}:{w}\n"
        ser.write(payload.encode())
        
        # Print monitoring log directly to terminal
        print(f"Sending Data Flow -> R: {r:<4} | G: {g:<4} | B: {b:<4} | W: {w:<4}", end="\r")
        
        # Control animation pacing loop rate (approx 50 updates per second)
        step += speed
        time.sleep(0.02)

except KeyboardInterrupt:
    # Graceful shutdown code on exit
    print("\n\nStopping script... Turning off LEDs.")
    ser.write(b"0:0:0:0\n")
    ser.close()

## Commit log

2025-06-22 file renaming
    [led_driver-B_Cu.gbr, led_driver-B_Mask.gbr, led_driver-B_Paste.gbr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]
2025-06-24 add partslib
    [ESP32-S3 Zero.step, led_driver_cc_v2.kicad_pcb, led_driver_cc_v2.kicad_sch]
2025-06-26 more custom parts
    [45206.3.stp, SLF10145T-470M1R4-PF.stp, led_driver_cc_v2.kicad_pcb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]
2025-06-26 step files in folders
    [ESP32-S3 Zero.step]
2025-06-28 removed lib
    [45206.3.stp, ESP32-S3 Zero.step, SLF10145T-470M1R4-PF.stp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]
2025-08-16 add new channels to led driver
    [led_driver_cc_v2.kicad_pcb, led_driver_cc_v2.kicad_sch]
2025-08-17 new channel arrangement
    [led_driver_cc_v2.kicad_pcb, led_driver_cc_v2.kicad_sch]
2026-02-07 add code
    [led_driver_cc_v1.kicad_pcb, led_driver_cc_v1.kicad_sch, led_driver_cc_v2.0.1.kicad_pcb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]
2026-03-19 add media and new foler structure
    [led_driver_cc_v2.0.1.kicad_pcb, led_driver_cc_v2.0.1.kicad_sch, led_driver_cv_v2.0.0.kicad_pcb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]
2026-03-20 ESP32 receiver and transmitter
2026-05-24 webserver example
    [led_driver_cc_v2.0.1.kicad_pcb, led_driver_cc_v2.0.1.kicad_sch, led_driver_cv_v2.0.0.kicad_pcb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]
2026-05-24 rework README
    [bom.csv, designators.csv, led_driver_cc_v2.0.1.kicad_pcb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]
2026-05-24 removed backups
    [bom.csv, designators.csv, positions.csv]
2026-05-24 Add 5A fuse to components list in README
